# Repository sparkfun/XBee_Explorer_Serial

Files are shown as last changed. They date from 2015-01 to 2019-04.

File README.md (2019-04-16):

SparkFun XBee Explorer Serial
==============================

SparkFun XBee Explorer Serial

[*SparkFun XBee Explorer Serial (WRL-13225)*](https://www.sparkfun.com/products/9111)

This is a RS232 to serial base unit for the XBee line. 
It works with all XBee units, including Series 1, Series 2.5, standard and Pro versions.

Repository Contents
-------------------

* **/Hardware** - All Eagle design files (.brd, .sch, .STL)
* **/Production** - Production panel files (.brd)

Documentation
--------------
* **[Hookup Guide](https://learn.sparkfun.com/tutorials/exploring-xbees-and-xctu)** - Basic hookup guide for the XBee Serial Explorer.
* **[SparkFun Fritzing repo](https://github.com/sparkfun/Fritzing_Parts)** - Fritzing diagrams for SparkFun products.
* **[SparkFun 3D Model repo](https://github.com/sparkfun/3D_Models)** - 3D models of SparkFun products. 

Product Versions
----------------
* [WRL-13225](https://www.sparkfun.com/products/13225)- Version 1.4. Currently for sale. 
* [RWRL-09111](https://www.sparkfun.com/products/retired/9111)- Version 1.2. Retired. 

GitHub Version History
---------------
* [v1.4](https://github.com/sparkfun/XBee_Explorer_Serial/tree/v1.4) - Version 1.4. Current files. 
* [v1.3](https://github.com/sparkfun/XBee_Explorer_Serial/tree/v1.3) - Version 1.3. Retired.  
* [v1.2](https://github.com/sparkfun/XBee_Explorer_Serial/tree/v1.2) - Version 1.2. Retired. 

License Information
-------------------

This product is _**open source**_! 

Please review the LICENSE.md file for license information. 

If you have any questions or concerns on licensing, please contact techsupport@sparkfun.com.

Distributed as-is; no warranty is given.

- Your friends at SparkFun.

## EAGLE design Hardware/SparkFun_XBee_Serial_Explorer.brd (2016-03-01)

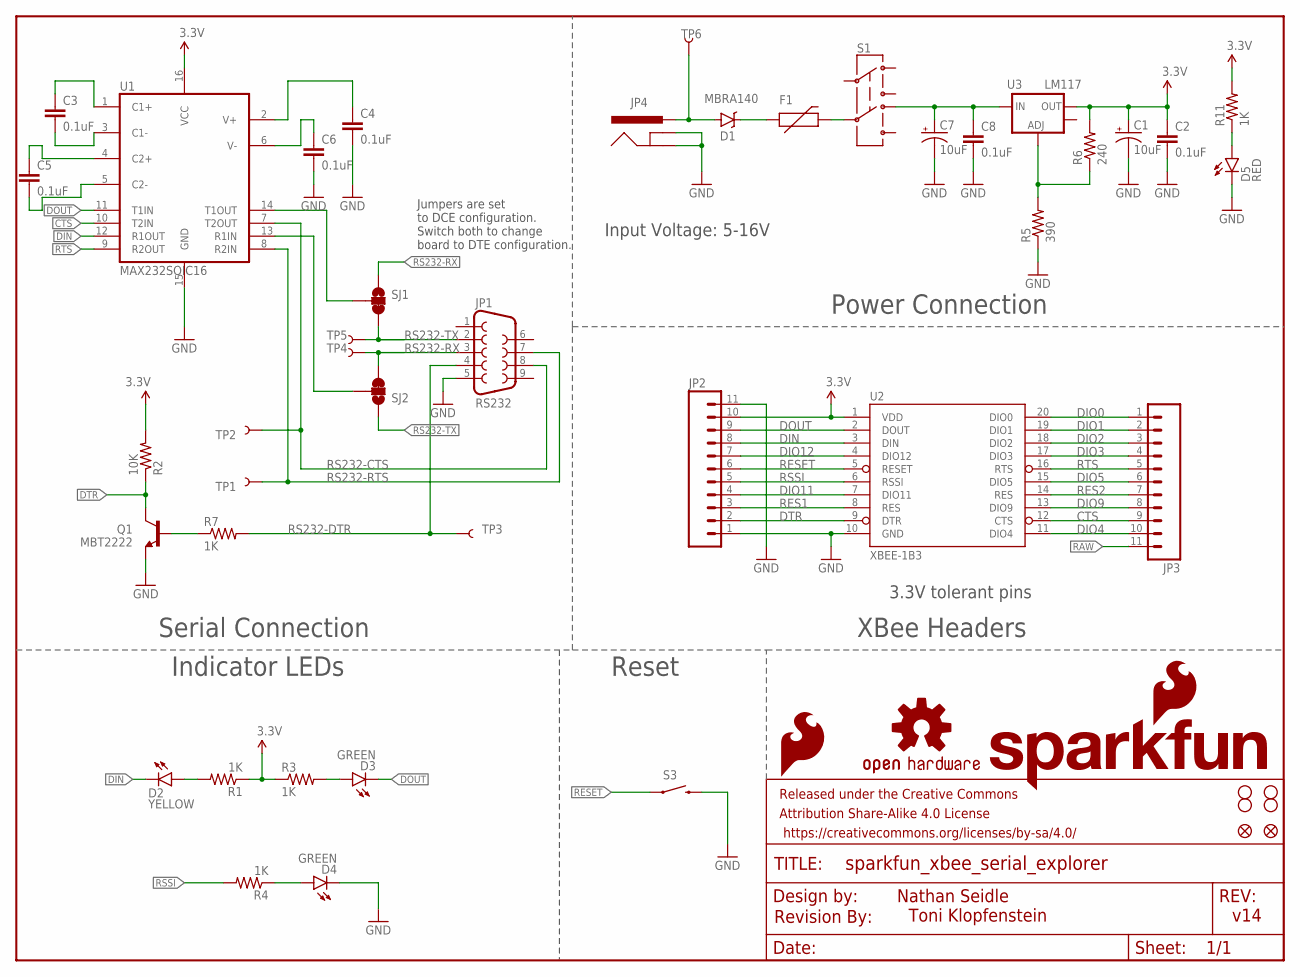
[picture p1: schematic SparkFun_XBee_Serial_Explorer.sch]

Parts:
C1, C7: 10uF; EIA3216
C2, C3, C4, C5, C6, C8: 0.1uF; 0603-CAP
D1: MBRA140; SMA-DIODE
D2: YELLOW; LED-1206
D3, D4: GREEN; LED-1206
D5: RED; LED-1206
F1: PTCTHERMISTOR1206; PTC-1206
FRAME1: FRAME-LETTER; CREATIVE_COMMONS
JP1: RS232; DB9
JP2, JP3: M11PTH; 1X11
JP4: POWER_JACKPTH_LOCK; POWER_JACK_PTH_LOCK
LOGO1: OSHW-LOGOL; OSHW-LOGO-L
LOGO2: SFE_LOGO_NAME_FLAME.2_INCH; SFE_LOGO_NAME_FLAME_.2
LOGO3: SFE_LOGO_FLAME.1_INCH; SFE_LOGO_FLAME_.1
Q1: MBT2222; SOT23-3
R1, R3, R4, R7, R11: 1K; 0603-RES
R2: 10K; 0603-RES
R5: 390; 0603-RES
R6: 240; 0603-RES
S1: AYZ0202
S3: TAC_SWITCHSMD; TACTILE-SWITCH-SMD
SJ1, SJ2: JUMPER-PAD-3-2OF3_NC_BY_TRACE_SMALL; PAD-JUMPER-3-2OF3_NC_BY_TRACE_YES_SILK_FULL_BOX
TP1, TP2, TP3, TP4, TP5, TP6: TEST-POINTTP_15TH_THRU; TP_15TH
U1: MAX232SOIC16; SO016
U2: XBEE-1B3; XBEE-SMD
U3: LM117; SOT223
U$1: REVISION
U$5, U$9, U$10, U$11: STAND-OFF
U$7, U$16: FIDUCIAL1X2; FIDUCIAL-1X2

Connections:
3.3V: C1.A (+), C2.1, JP2.10, R1.1, R2.2, R3.1, R6.2, R11.2, U1.16 (VCC), U2.1 (VDD), U3.2 (OUT)
CTS: JP3.9, U1.10 (T2IN), U2.12 (CTS)
DIN: D2.C, JP2.8, U1.12 (R1OUT), U2.3 (DIN)
DIO0: JP3.1, U2.20 (DIO0)
DIO1: JP3.2, U2.19 (DIO1)
DIO2: JP3.3, U2.18 (DIO2)
DIO3: JP3.4, U2.17 (DIO3)
DIO4: JP3.10, U2.11 (DIO4)
DIO5: JP3.6, U2.15 (DIO5)
DIO9: JP3.8, U2.13 (DIO9)
DIO11: JP2.4, U2.7 (DIO11)
DIO12: JP2.7, U2.4 (DIO12)
DOUT: D3.C, JP2.9, U1.11 (T1IN), U2.2 (DOUT)
DTR: JP2.2, Q1.3 (C), R2.1, U2.9 (DTR)
GND: C1.C (-), C2.2, C4.2, C6.2, C7.C (-), C8.2, D4.C, D5.C, JP1.5, JP2.1, JP2.11, JP4.GND, JP4.GNDBREAK, Q1.2 (E), R5.1, S3.3 (2), S3.4 (2), U1.15 (GND), U2.10 (GND)
unnamed: D2.A, R1.2
unnamed: D4.A, R4.1
unnamed: C3.1, U1.1 (C1+)
unnamed: D3.A, R3.2
unnamed: C3.2, U1.3 (C1-)
unnamed: C5.1, U1.4 (C2+)
unnamed: C5.2, U1.5 (C2-)
unnamed: C6.1, U1.6 (V-)
unnamed: C4.1, U1.2 (V+)
unnamed: R5.2, R6.1, U3.1 (ADJ)
unnamed: F1.2, S1.5
unnamed: Q1.1 (B), R7.1
unnamed: SJ2.2, U1.13 (R1IN)
unnamed: SJ1.2, U1.14 (T1OUT)
unnamed: D1.A, JP4.PWR, TP6.P$1
unnamed: D1.C, F1.1
unnamed: D5.A, R11.1
RAW: C7.A (+), C8.1, JP3.11, S1.6 (4), U3.3 (IN)
RES1: JP2.3, U2.8 (RES)
RES2: JP3.7, U2.14 (RES)
RESET: JP2.6, S3.1, S3.2 (1), U2.5 (RESET)
RS232-CTS: JP1.8, TP2.P$1, U1.7 (T2OUT)
RS232-DTR: JP1.4, R7.2, TP3.P$1
RS232-RTS: JP1.7, TP1.P$1, U1.8 (R2IN)
RS232-RX: JP1.3, SJ1.1, SJ2.3, TP4.P$1
RS232-TX: JP1.2, SJ1.3, SJ2.1, TP5.P$1
RSSI: JP2.5, R4.2, U2.6 (RSSI)
RTS: JP3.5, U1.9 (R2OUT), U2.16 (RTS)

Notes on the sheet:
v14
Nathan Seidle
Toni Klopfenstein
Jumpers are set to DCE configuration. Switch both to change board to DTE configuration.
Input Voltage: 5-16V
3.3V tolerant pins
Serial Connection
Power Connection
XBee Headers
Reset
Indicator LEDs

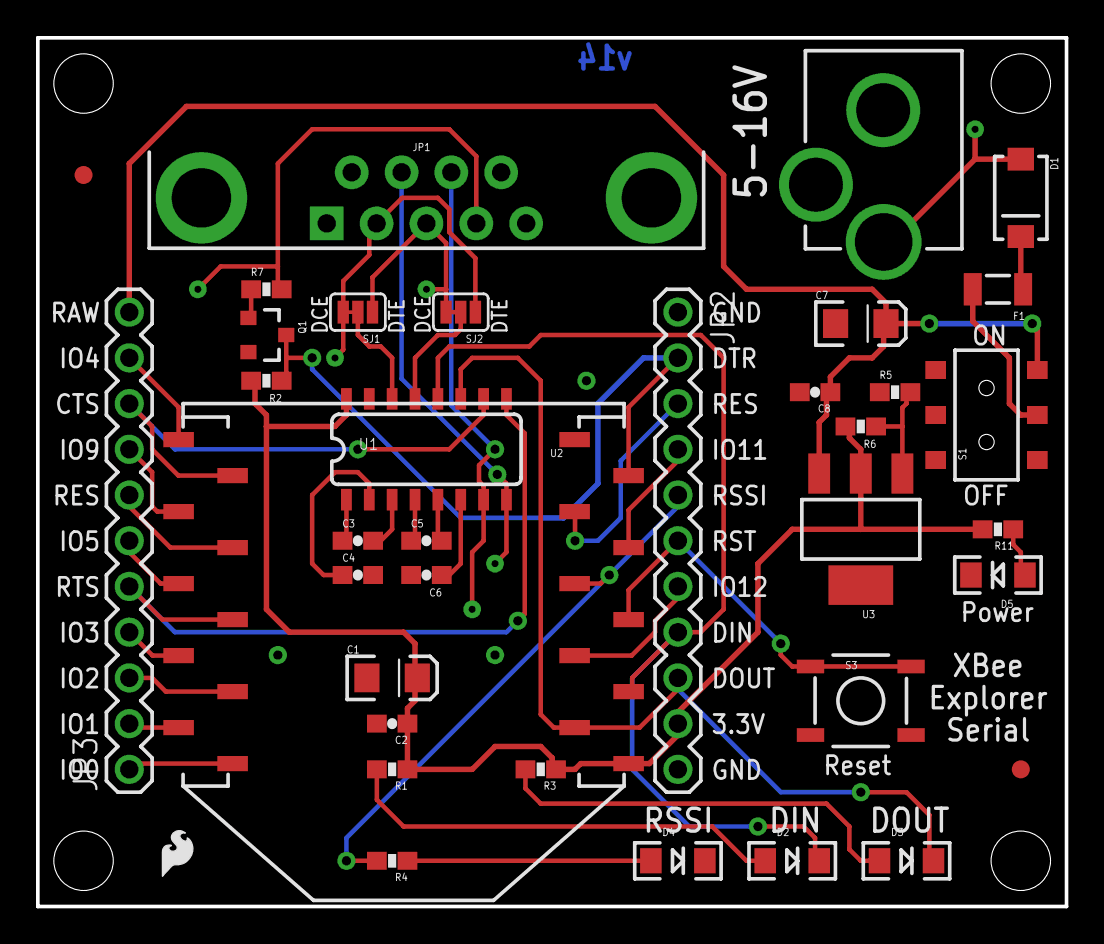
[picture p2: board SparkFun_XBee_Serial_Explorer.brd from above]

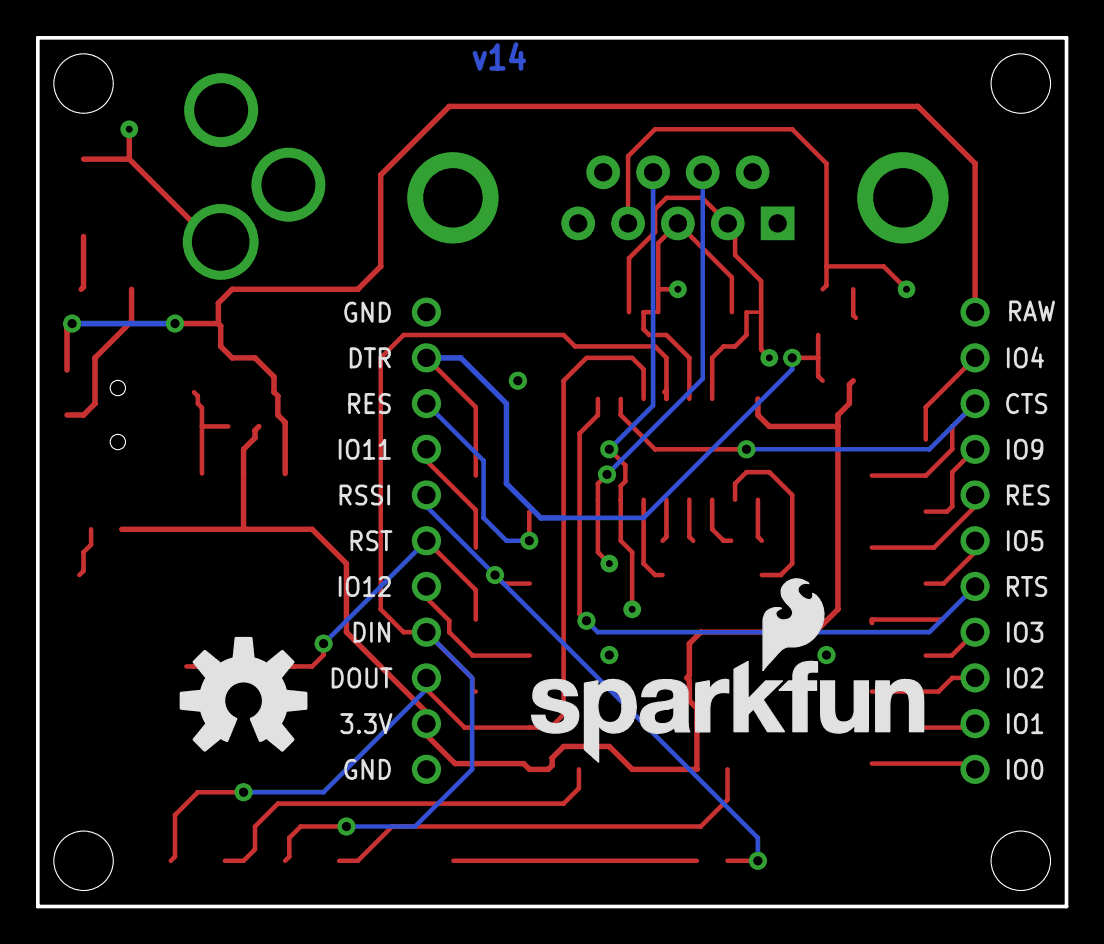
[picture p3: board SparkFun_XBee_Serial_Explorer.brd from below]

Board: 2 copper layers, 57.1 x 48.3 mm, 51 parts (2 on the bottom side), 43 nets.

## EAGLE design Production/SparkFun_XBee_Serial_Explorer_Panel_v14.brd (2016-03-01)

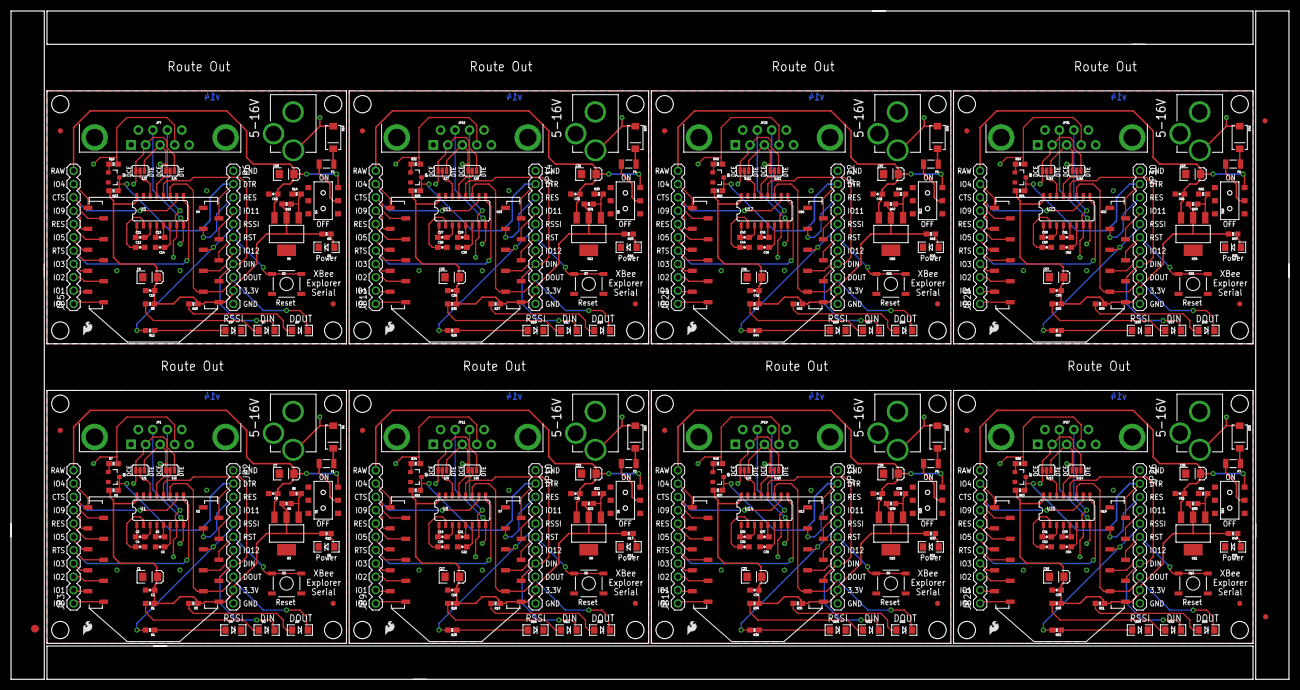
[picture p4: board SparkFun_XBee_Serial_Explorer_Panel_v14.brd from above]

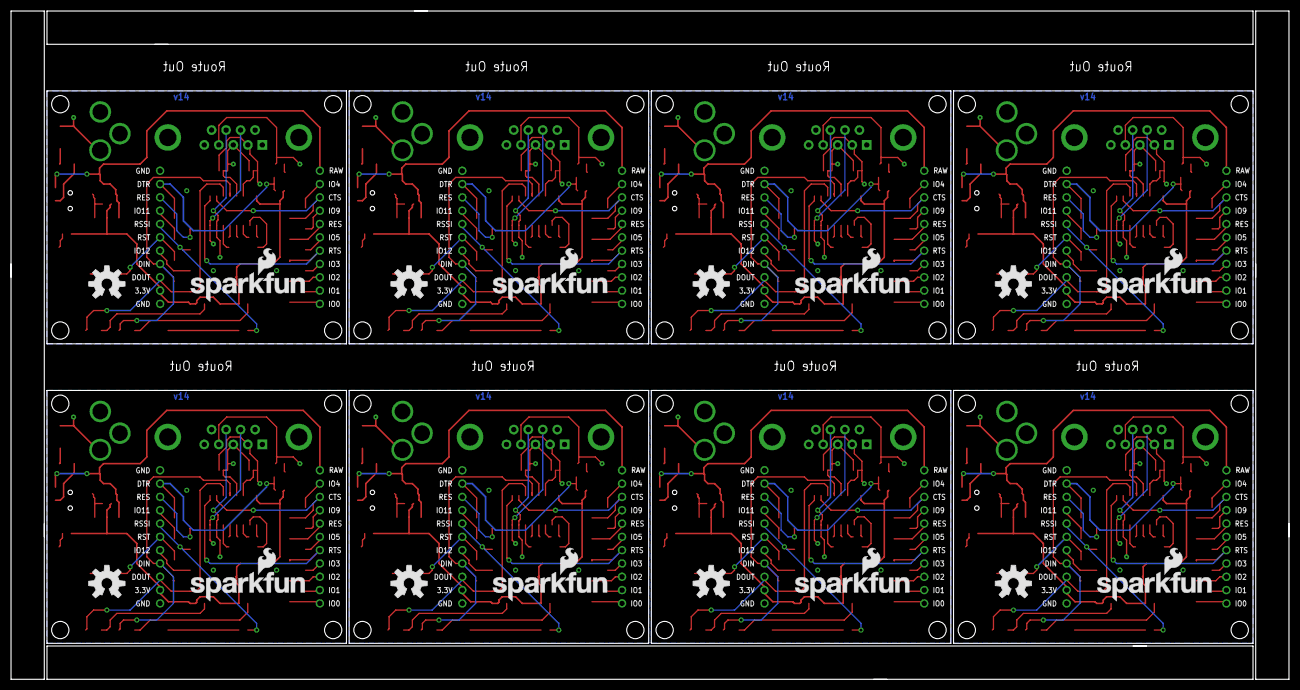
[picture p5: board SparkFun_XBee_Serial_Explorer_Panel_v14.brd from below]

Board: 2 copper layers, 243.8 x 127.5 mm, 395 parts (16 on the bottom side), 344 nets.

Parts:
C1, C7, C9, C15, C17, C23, C25, C31, C33, C39, C41, C47, C49, C55, C57, C63: 10uF; EIA3216
C2, C3, C4, C5, C6, C8, C10, C11, C12, C13, C14, C16, C18, C19, C20, C21, C22, C24, C26, C27, C28, C29, C30, C32, C34, C35, C36, C37, C38, C40, C42, C43, C44, C45, C46, C48, C50, C51, C52, C53, C54, C56, C58, C59, C60, C61, C62, C64: 0.1uF; 0603-CAP
D1, D10, D15, D20, D25, D30, D35, D40: MBRA140; SMA-DIODE
D2, D7, D12, D17, D22, D27, D32, D37: YELLOW; LED-1206
D3, D4, D8, D9, D13, D14, D18, D19, D23, D24, D28, D29, D33, D34, D38, D39: GREEN; LED-1206
D5, D6, D11, D16, D21, D26, D31, D36: RED; LED-1206
E$1: FIDUCIAL-1.5X3
E$5, E$6: FIDUCIAL-1X2
F1, F2, F3, F4, F5, F6, F7, F8: PTCTHERMISTOR1206; PTC-1206
JP1, JP7, JP11, JP15, JP19, JP23, JP27, JP31: RS232; DB9
JP2, JP3, JP5, JP6, JP9, JP10, JP13, JP14, JP17, JP18, JP21, JP22, JP25, JP26, JP29, JP30: 1X11
JP4, JP8, JP12, JP16, JP20, JP24, JP28, JP32: POWER_JACKPTH_LOCK; POWER_JACK_PTH_LOCK
LOGO1, LOGO4, LOGO7, LOGO10, LOGO13, LOGO16, LOGO19, LOGO22: OSHW-LOGOL; OSHW-LOGO-L
LOGO2, LOGO5, LOGO8, LOGO11, LOGO14, LOGO17, LOGO20, LOGO23: SFE_LOGO_NAME_FLAME.2_INCH; SFE_LOGO_NAME_FLAME_.2
LOGO3, LOGO6, LOGO9, LOGO12, LOGO15, LOGO18, LOGO21, LOGO24: SFE_LOGO_FLAME.1_INCH; SFE_LOGO_FLAME_.1
Q1, Q2, Q3, Q4, Q5, Q6, Q7, Q8: MBT2222; SOT23-3
R1, R3, R4, R7, R8, R9, R10, R11, R12, R16, R17, R18, R19, R20, R24, R25, R26, R27, R28, R32, R33, R34, R35, R36, R40, R41, R42, R43, R44, R48, R49, R50, R51, R52, R56, R57, R58, R59, R60, R64: 1K; 0603-RES
R2, R13, R21, R29, R37, R45, R53, R61: 10K; 0603-RES
R5, R14, R22, R30, R38, R46, R54, R62: 390; 0603-RES
R6, R15, R23, R31, R39, R47, R55, R63: 240; 0603-RES
S1, S4, S6, S8, S10, S12, S14, S16: AYZ0202
S2, S3, S5, S7, S9, S11, S13, S15: TAC_SWITCHSMD; TACTILE-SWITCH-SMD
SJ1, SJ2, SJ3, SJ4, SJ5, SJ6, SJ7, SJ8, SJ9, SJ10, SJ11, SJ12, SJ13, SJ14, SJ15, SJ16: JUMPER-PAD-3-2OF3_NC_BY_TRACE_SMALL; PAD-JUMPER-3-2OF3_NC_BY_TRACE_YES_SILK_FULL_BOX
TP1, TP2, TP3, TP4, TP5, TP6, TP7, TP8, TP9, TP10, TP11, TP12, TP13, TP14, TP15, TP16, TP17, TP18, TP19, TP20, TP21, TP22, TP23, TP24, TP25, TP26, TP27, TP28, TP29, TP30, TP31, TP32, TP33, TP34, TP35, TP36, TP37, TP38, TP39, TP40, TP41, TP42, TP43, TP44, TP45, TP46, TP47, TP48: TEST-POINTTP_15TH_THRU; TP_15TH
U1, U5, U8, U11, U14, U17, U20, U23: MAX232SOIC16; SO016
U2, U4, U7, U10, U13, U16, U19, U22: XBEE-1B3; XBEE-SMD
U3, U6, U9, U12, U15, U18, U21, U24: LM117; SOT223
U$1, U$2, U$7, U$12, U$13, U$16, U$19, U$20, U$25, U$26, U$31, U$32, U$37, U$38, U$43, U$44: FIDUCIAL1X2; FIDUCIAL-1X2
U$3, U$4, U$5, U$6, U$8, U$9, U$10, U$11, U$14, U$15, U$17, U$18, U$21, U$22, U$23, U$24, U$27, U$28, U$29, U$30, U$33, U$34, U$35, U$36, U$39, U$40, U$41, U$42, U$45, U$46, U$47, U$48: STAND-OFF

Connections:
3.3V: C1.A, C2.1, JP2.10, R1.1, R2.2, R3.1, R6.2, R11.2, U1.16, U2.1, U3.2
3.3V1: C9.A, C10.1, JP6.10, R8.2, R9.1, R10.1, R13.2, R15.2, U4.1, U5.16, U6.2
3.3V2: C17.A, C18.1, JP10.10, R17.2, R18.1, R19.1, R21.2, R23.2, U7.1, U8.16, U9.2
3.3V3: C25.A, C26.1, JP14.10, R25.2, R26.1, R27.1, R29.2, R31.2, U10.1, U11.16, U12.2
3.3V4: C33.A, C34.1, JP18.10, R33.2, R34.1, R35.1, R37.2, R39.2, U13.1, U14.16, U15.2
3.3V5: C41.A, C42.1, JP22.10, R41.2, R42.1, R43.1, R45.2, R47.2, U16.1, U17.16, U18.2
3.3V6: C49.A, C50.1, JP26.10, R49.2, R50.1, R51.1, R53.2, R55.2, U19.1, U20.16, U21.2
3.3V7: C57.A, C58.1, JP30.10, R57.2, R58.1, R59.1, R61.2, R63.2, U22.1, U23.16, U24.2
CTS: JP3.9, U1.10, U2.12
CTS1: JP5.9, U4.12, U5.10
CTS2: JP9.9, U7.12, U8.10
CTS3: JP13.9, U10.12, U11.10
CTS4: JP17.9, U13.12, U14.10
CTS5: JP21.9, U16.12, U17.10
CTS6: JP25.9, U19.12, U20.10
CTS7: JP29.9, U22.12, U23.10
DIN: D2.C, JP2.8, U1.12, U2.3
DIN1: D7.C, JP6.8, U4.3, U5.12
DIN2: D12.C, JP10.8, U7.3, U8.12
DIN3: D17.C, JP14.8, U10.3, U11.12
DIN4: D22.C, JP18.8, U13.3, U14.12
DIN5: D27.C, JP22.8, U16.3, U17.12
DIN6: D32.C, JP26.8, U19.3, U20.12
DIN7: D37.C, JP30.8, U22.3, U23.12
DIO0: JP3.1, U2.20
DIO1: JP3.2, U2.19
DIO2: JP3.3, U2.18
DIO3: JP3.4, U2.17
DIO4: JP3.10, U2.11
DIO5: JP3.6, U2.15
DIO6: JP5.10, U4.11
DIO7: JP5.8, U4.13
DIO8: JP5.6, U4.15
DIO9: JP3.8, U2.13
DIO10: JP5.4, U4.17
DIO11: JP2.4, U2.7
DIO12: JP2.7, U2.4
DIO13: JP5.3, U4.18
DIO14: JP5.2, U4.19
DIO15: JP5.1, U4.20
DIO16: JP6.4, U4.7
DIO17: JP6.7, U4.4
DIO18: JP9.10, U7.11
DIO19: JP9.8, U7.13
DIO20: JP9.6, U7.15
DIO21: JP9.4, U7.17
DIO22: JP9.3, U7.18
DIO23: JP9.2, U7.19
DIO24: JP9.1, U7.20
DIO25: JP10.4, U7.7
DIO26: JP10.7, U7.4
DIO27: JP13.10, U10.11
DIO28: JP13.8, U10.13
DIO29: JP13.6, U10.15
DIO30: JP13.4, U10.17
DIO31: JP13.3, U10.18
DIO32: JP13.2, U10.19
DIO33: JP13.1, U10.20
DIO34: JP14.4, U10.7
DIO35: JP14.7, U10.4
DIO36: JP17.10, U13.11
DIO37: JP17.8, U13.13
DIO38: JP17.6, U13.15
DIO39: JP17.4, U13.17
DIO40: JP17.3, U13.18
DIO41: JP17.2, U13.19
DIO42: JP17.1, U13.20
DIO43: JP18.4, U13.7
DIO44: JP18.7, U13.4
DIO45: JP21.10, U16.11
DIO46: JP21.8, U16.13
DIO47: JP21.6, U16.15
DIO48: JP21.4, U16.17
DIO49: JP21.3, U16.18
DIO50: JP21.2, U16.19
DIO51: JP21.1, U16.20
DIO52: JP22.4, U16.7
DIO53: JP22.7, U16.4
DIO54: JP25.10, U19.11
DIO55: JP25.8, U19.13
DIO56: JP25.6, U19.15
DIO57: JP25.4, U19.17
DIO58: JP25.3, U19.18
DIO59: JP25.2, U19.19
DIO60: JP25.1, U19.20
DIO61: JP26.4, U19.7
DIO62: JP26.7, U19.4
DIO63: JP29.10, U22.11
DIO64: JP29.8, U22.13
DIO65: JP29.6, U22.15
DIO66: JP29.4, U22.17
DIO67: JP29.3, U22.18
DIO68: JP29.2, U22.19
DIO69: JP29.1, U22.20
DIO70: JP30.4, U22.7
DIO71: JP30.7, U22.4
DOUT: D3.C, JP2.9, U1.11, U2.2
DOUT1: D8.C, JP6.9, U4.2, U5.11
DOUT2: D13.C, JP10.9, U7.2, U8.11
DOUT3: D18.C, JP14.9, U10.2, U11.11
DOUT4: D23.C, JP18.9, U13.2, U14.11
DOUT5: D28.C, JP22.9, U16.2, U17.11
DOUT6: D33.C, JP26.9, U19.2, U20.11
DOUT7: D38.C, JP30.9, U22.2, U23.11
DTR: JP2.2, Q1.3, R2.1, U2.9
DTR1: JP6.2, Q2.3, R13.1, U4.9
DTR2: JP10.2, Q3.3, R21.1, U7.9
DTR3: JP14.2, Q4.3, R29.1, U10.9
DTR4: JP18.2, Q5.3, R37.1, U13.9
DTR5: JP22.2, Q6.3, R45.1, U16.9
DTR6: JP26.2, Q7.3, R53.1, U19.9
DTR7: JP30.2, Q8.3, R61.1, U22.9
GND: C1.C, C2.2, C4.2, C6.2, C7.C, C8.2, D4.C, D5.C, JP1.5, JP2.1, JP2.11, JP4.GND, JP4.GNDBREAK, Q1.2, R5.1, S3.3, S3.4, U1.15, U2.10
GND1: C9.C, C10.2, C12.2, C14.2, C15.C, C16.2, D6.C, D9.C, JP6.1, JP6.11, JP7.5, JP8.GND, JP8.GNDBREAK, Q2.2, R14.1, S2.3, S2.4, U4.10, U5.15
GND2: C17.C, C18.2, C20.2, C22.2, C23.C, C24.2, D11.C, D14.C, JP10.1, JP10.11, JP11.5, JP12.GND, JP12.GNDBREAK, Q3.2, R22.1, S5.3, S5.4, U7.10, U8.15
GND3: C25.C, C26.2, C28.2, C30.2, C31.C, C32.2, D16.C, D19.C, JP14.1, JP14.11, JP15.5, JP16.GND, JP16.GNDBREAK, Q4.2, R30.1, S7.3, S7.4, U10.10, U11.15
GND4: C33.C, C34.2, C36.2, C38.2, C39.C, C40.2, D21.C, D24.C, JP18.1, JP18.11, JP19.5, JP20.GND, JP20.GNDBREAK, Q5.2, R38.1, S9.3, S9.4, U13.10, U14.15
GND5: C41.C, C42.2, C44.2, C46.2, C47.C, C48.2, D26.C, D29.C, JP22.1, JP22.11, JP23.5, JP24.GND, JP24.GNDBREAK, Q6.2, R46.1, S11.3, S11.4, U16.10, U17.15
GND6: C49.C, C50.2, C52.2, C54.2, C55.C, C56.2, D31.C, D34.C, JP26.1, JP26.11, JP27.5, JP28.GND, JP28.GNDBREAK, Q7.2, R54.1, S13.3, S13.4, U19.10, U20.15
GND7: C57.C, C58.2, C60.2, C62.2, C63.C, C64.2, D36.C, D39.C, JP30.1, JP30.11, JP31.5, JP32.GND, JP32.GNDBREAK, Q8.2, R62.1, S15.3, S15.4, U22.10, U23.15
unnamed: D2.A, R1.2
unnamed: D4.A, R4.1
unnamed: C3.1, U1.1
unnamed: D3.A, R3.2
unnamed: C3.2, U1.3
unnamed: C5.1, U1.4
unnamed: C5.2, U1.5
unnamed: C6.1, U1.6
unnamed: C4.1, U1.2
unnamed: R5.2, R6.1, U3.1
unnamed: F1.2, S1.5
unnamed: Q1.1, R7.1
unnamed: SJ2.2, U1.13
unnamed: SJ1.2, U1.14
unnamed: D1.A, JP4.PWR, TP6.P$1
unnamed: D1.C, F1.1
unnamed: D6.A, R8.1
unnamed: D7.A, R9.2
unnamed: D8.A, R10.2
unnamed: D9.A, R12.1
unnamed: C11.2, U5.3
unnamed: C13.1, U5.4
unnamed: C13.2, U5.5
unnamed: C14.1, U5.6
unnamed: C12.1, U5.2
unnamed: C11.1, U5.1
unnamed: D10.A, JP8.PWR, TP12.P$1
unnamed: D10.C, F2.1
unnamed: R14.2, R15.1, U6.1
unnamed: F2.2, S4.5
unnamed: Q2.1, R16.1
unnamed: SJ4.2, U5.13
unnamed: SJ3.2, U5.14
unnamed: D11.A, R17.1
unnamed: D12.A, R18.2
unnamed: D13.A, R19.2
unnamed: D14.A, R20.1
unnamed: D5.A, R11.1
unnamed: C19.2, U8.3
unnamed: C21.1, U8.4
unnamed: C21.2, U8.5
unnamed: C22.1, U8.6
unnamed: C20.1, U8.2
unnamed: C19.1, U8.1
unnamed: D15.A, JP12.PWR, TP18.P$1
unnamed: D15.C, F3.1
unnamed: R22.2, R23.1, U9.1
unnamed: F3.2, S6.5
unnamed: Q3.1, R24.1
unnamed: SJ6.2, U8.13
unnamed: SJ5.2, U8.14
unnamed: D16.A, R25.1
unnamed: D17.A, R26.2
unnamed: D18.A, R27.2
unnamed: D19.A, R28.1
unnamed: C27.2, U11.3
unnamed: C29.1, U11.4
unnamed: C29.2, U11.5
unnamed: C30.1, U11.6
unnamed: C28.1, U11.2
unnamed: C27.1, U11.1
unnamed: D20.A, JP16.PWR, TP24.P$1
unnamed: D20.C, F4.1
unnamed: R30.2, R31.1, U12.1
unnamed: F4.2, S8.5
unnamed: Q4.1, R32.1
unnamed: SJ8.2, U11.13
unnamed: SJ7.2, U11.14
unnamed: D21.A, R33.1
unnamed: D22.A, R34.2
unnamed: D23.A, R35.2
unnamed: D24.A, R36.1
unnamed: C35.2, U14.3
unnamed: C37.1, U14.4
unnamed: C37.2, U14.5
unnamed: C38.1, U14.6
unnamed: C36.1, U14.2
unnamed: C35.1, U14.1
unnamed: D25.A, JP20.PWR, TP30.P$1
unnamed: D25.C, F5.1
unnamed: R38.2, R39.1, U15.1
unnamed: F5.2, S10.5
unnamed: Q5.1, R40.1
unnamed: SJ10.2, U14.13
unnamed: SJ9.2, U14.14
unnamed: D26.A, R41.1
unnamed: D27.A, R42.2
unnamed: D28.A, R43.2
unnamed: D29.A, R44.1
unnamed: C43.2, U17.3
unnamed: C45.1, U17.4
unnamed: C45.2, U17.5
unnamed: C46.1, U17.6
unnamed: C44.1, U17.2
unnamed: C43.1, U17.1
unnamed: D30.A, JP24.PWR, TP36.P$1
unnamed: D30.C, F6.1
unnamed: R46.2, R47.1, U18.1
unnamed: F6.2, S12.5
unnamed: Q6.1, R48.1
unnamed: SJ12.2, U17.13
unnamed: SJ11.2, U17.14
unnamed: D31.A, R49.1
unnamed: D32.A, R50.2
unnamed: D33.A, R51.2
unnamed: D34.A, R52.1
unnamed: C51.2, U20.3
unnamed: C53.1, U20.4
unnamed: C53.2, U20.5
unnamed: C54.1, U20.6
unnamed: C52.1, U20.2
unnamed: C51.1, U20.1
unnamed: D35.A, JP28.PWR, TP42.P$1
unnamed: D35.C, F7.1
unnamed: R54.2, R55.1, U21.1
unnamed: F7.2, S14.5
unnamed: Q7.1, R56.1
unnamed: SJ14.2, U20.13
unnamed: SJ13.2, U20.14
unnamed: D36.A, R57.1
unnamed: D37.A, R58.2
unnamed: D38.A, R59.2
unnamed: D39.A, R60.1
unnamed: C59.2, U23.3
unnamed: C61.1, U23.4
unnamed: C61.2, U23.5
unnamed: C62.1, U23.6
unnamed: C60.1, U23.2
unnamed: C59.1, U23.1
unnamed: D40.A, JP32.PWR, TP48.P$1
unnamed: D40.C, F8.1
unnamed: R62.2, R63.1, U24.1
unnamed: F8.2, S16.5
unnamed: Q8.1, R64.1
unnamed: SJ16.2, U23.13
unnamed: SJ15.2, U23.14
RAW: C7.A, C8.1, JP3.11, S1.6, U3.3
RAW1: C15.A, C16.1, JP5.11, S4.6, U6.3
RAW2: C23.A, C24.1, JP9.11, S6.6, U9.3
RAW3: C31.A, C32.1, JP13.11, S8.6, U12.3
RAW4: C39.A, C40.1, JP17.11, S10.6, U15.3
RAW5: C47.A, C48.1, JP21.11, S12.6, U18.3
RAW6: C55.A, C56.1, JP25.11, S14.6, U21.3
RAW7: C63.A, C64.1, JP29.11, S16.6, U24.3
RES1: JP2.3, U2.8
RES2: JP3.7, U2.14
RES3: JP6.3, U4.8
RES4: JP5.7, U4.14
RES5: JP10.3, U7.8
RES6: JP9.7, U7.14
RES7: JP14.3, U10.8
RES8: JP13.7, U10.14
RES9: JP18.3, U13.8
RES10: JP17.7, U13.14
RES11: JP22.3, U16.8
RES12: JP21.7, U16.14
RES13: JP26.3, U19.8
RES14: JP25.7, U19.14
RES15: JP30.3, U22.8
RES16: JP29.7, U22.14
RESET: JP2.6, S3.1, S3.2, U2.5
RESET1: JP6.6, S2.1, S2.2, U4.5
RESET2: JP10.6, S5.1, S5.2, U7.5
RESET3: JP14.6, S7.1, S7.2, U10.5
RESET4: JP18.6, S9.1, S9.2, U13.5
RESET5: JP22.6, S11.1, S11.2, U16.5
RESET6: JP26.6, S13.1, S13.2, U19.5
RESET7: JP30.6, S15.1, S15.2, U22.5
RS232-CTS: JP1.8, TP2.P$1, U1.7
RS232-CTS1: JP7.8, TP8.P$1, U5.7
RS232-CTS2: JP11.8, TP14.P$1, U8.7
RS232-CTS3: JP15.8, TP20.P$1, U11.7
RS232-CTS4: JP19.8, TP26.P$1, U14.7
RS232-CTS5: JP23.8, TP32.P$1, U17.7
RS232-CTS6: JP27.8, TP38.P$1, U20.7
RS232-CTS7: JP31.8, TP44.P$1, U23.7
RS232-DTR: JP1.4, R7.2, TP3.P$1
RS232-DTR1: JP7.4, R16.2, TP9.P$1
RS232-DTR2: JP11.4, R24.2, TP15.P$1
RS232-DTR3: JP15.4, R32.2, TP21.P$1
RS232-DTR4: JP19.4, R40.2, TP27.P$1
RS232-DTR5: JP23.4, R48.2, TP33.P$1
RS232-DTR6: JP27.4, R56.2, TP39.P$1
RS232-DTR7: JP31.4, R64.2, TP45.P$1
RS232-RTS: JP1.7, TP1.P$1, U1.8
RS232-RTS1: JP7.7, TP7.P$1, U5.8
RS232-RTS2: JP11.7, TP13.P$1, U8.8
RS232-RTS3: JP15.7, TP19.P$1, U11.8
RS232-RTS4: JP19.7, TP25.P$1, U14.8
RS232-RTS5: JP23.7, TP31.P$1, U17.8
RS232-RTS6: JP27.7, TP37.P$1, U20.8
RS232-RTS7: JP31.7, TP43.P$1, U23.8
RS232-RX: JP1.3, SJ1.1, SJ2.3, TP4.P$1
RS232-RX1: JP7.3, SJ3.1, SJ4.3, TP10.P$1
RS232-RX2: JP11.3, SJ5.1, SJ6.3, TP16.P$1
RS232-RX3: JP15.3, SJ7.1, SJ8.3, TP22.P$1
RS232-RX4: JP19.3, SJ9.1, SJ10.3, TP28.P$1
RS232-RX5: JP23.3, SJ11.1, SJ12.3, TP34.P$1
RS232-RX6: JP27.3, SJ13.1, SJ14.3, TP40.P$1
RS232-RX7: JP31.3, SJ15.1, SJ16.3, TP46.P$1
RS232-TX: JP1.2, SJ1.3, SJ2.1, TP5.P$1
RS232-TX1: JP7.2, SJ3.3, SJ4.1, TP11.P$1
RS232-TX2: JP11.2, SJ5.3, SJ6.1, TP17.P$1
RS232-TX3: JP15.2, SJ7.3, SJ8.1, TP23.P$1
RS232-TX4: JP19.2, SJ9.3, SJ10.1, TP29.P$1
RS232-TX5: JP23.2, SJ11.3, SJ12.1, TP35.P$1
RS232-TX6: JP27.2, SJ13.3, SJ14.1, TP41.P$1
RS232-TX7: JP31.2, SJ15.3, SJ16.1, TP47.P$1
RSSI: JP2.5, R4.2, U2.6
RSSI1: JP6.5, R12.2, U4.6
RSSI2: JP10.5, R20.2, U7.6
RSSI3: JP14.5, R28.2, U10.6
RSSI4: JP18.5, R36.2, U13.6
RSSI5: JP22.5, R44.2, U16.6
RSSI6: JP26.5, R52.2, U19.6
RSSI7: JP30.5, R60.2, U22.6
RTS: JP3.5, U1.9, U2.16
RTS1: JP5.5, U4.16, U5.9
RTS2: JP9.5, U7.16, U8.9
RTS3: JP13.5, U10.16, U11.9
RTS4: JP17.5, U13.16, U14.9
RTS5: JP21.5, U16.16, U17.9
RTS6: JP25.5, U19.16, U20.9
RTS7: JP29.5, U22.16, U23.9

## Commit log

2014-11-07 Initial hardware files added and README updated.
    [SparkFun-XBee-Serial-Explorer-v12.brd, SparkFun-XBee-Serial-Explorer-v12.sch]
2014-11-08 Initial schematic updates to new library parts
    [SparkFun-XBee-Serial-Explorer-v12.brd, SparkFun-XBee-Serial-Explorer-v12.sch, SparkFun_XBee_Serial_Explorer.brd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]
2014-11-11 Board rev in progress
    [SparkFun_XBee_Serial_Explorer.brd, SparkFun_XBee_Serial_Explorer.sch]
2014-11-13 Rerouting, updating parts to PTH, add dimensions, etc.
    [SparkFun_XBee_Serial_Explorer.brd, SparkFun_XBee_Serial_Explorer.sch]
2014-11-18 Updating board and schematic to address GitHub issues
    [SparkFun_XBee_Serial_Explorer.brd, SparkFun_XBee_Serial_Explorer.sch]
2014-11-19 Fixes for QC checklist
    [SparkFun_XBee_Serial_Explorer.brd, SparkFun_XBee_Serial_Explorer.sch]
2014-11-19 Moving barrel jack silk
    [SparkFun_XBee_Serial_Explorer.brd, SparkFun_XBee_Serial_Explorer.sch]
2014-11-21 Adding in test points for QC
    [SparkFun_XBee_Serial_Explorer.brd, SparkFun_XBee_Serial_Explorer.sch]
2014-11-21 Fixing PTC part number for proper BOM
    [SparkFun_XBee_Serial_Explorer.brd, SparkFun_XBee_Serial_Explorer.sch]
2014-12-29 Moving test points away from selective solder points/moving board name
    [SparkFun_XBee_Serial_Explorer.brd]
2014-12-30 Final QC checklist and changes for testbed
    [SparkFun_XBee_Serial_Explorer.brd, SparkFun_XBee_Serial_Explorer.sch]
2015-01-07 moved fids slightly
    [SparkFun_XBee_Serial_Explorer.brd]
2015-01-07 created v13 giant panel
    [SparkFun_XBee_Serial_Explorer_GiantPanel_v13.brd]
2015-10-27 Update repo structure, readme with new product info, add license file
    [SparkFun_XBee_Serial_Explorer_GiantPanel_v13.brd]
2016-02-12 Fixing jumper trace, updating version number
    [SparkFun_XBee_Serial_Explorer.brd, SparkFun_XBee_Serial_Explorer.sch]
2016-03-01 Fixing silk logos to prevent large plot data issues
    [SparkFun_XBee_Serial_Explorer.brd, SparkFun_XBee_Serial_Explorer.sch]
2016-03-01 created panel v14
    [SparkFun_XBee_Serial_Explorer_Panel_v14.brd]

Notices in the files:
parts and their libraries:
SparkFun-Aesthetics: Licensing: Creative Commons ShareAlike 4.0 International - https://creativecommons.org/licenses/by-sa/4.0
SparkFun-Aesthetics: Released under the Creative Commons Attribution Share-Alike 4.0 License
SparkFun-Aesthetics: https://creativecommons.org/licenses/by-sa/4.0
